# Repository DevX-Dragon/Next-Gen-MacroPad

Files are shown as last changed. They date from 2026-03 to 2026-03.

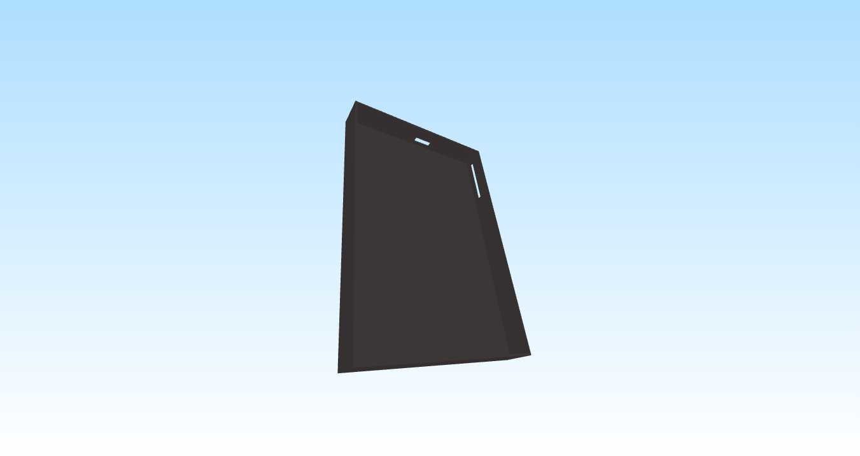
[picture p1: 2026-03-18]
images/Bottom Enclosure.png

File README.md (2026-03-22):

# NextGen Macropad
The Next-Gen MacroPad is a fully DIY, multi-purpose macro pad kit. It's got programmable keys, it looks cool, and most importantly — I made it. A 14-year-old made it. So if it breaks, don't be too surprised, but also it probably won't break because I tested it a bunch.

## Specifications
- 16 Programmable Keys
- 0.96 OLED Display
- Both Bluetooth and USB C connectivity
- Per Key RGB

## Layout
### KiCad
Schematics
PCB

### 3D
Bottom Enclosure
Top Cover

### Assembled
Assembled Preview
Side Side Loo

## Whats inside?
- `/3D Files` : 3D Files for 3D Printing and Source Files for your own modifcations.
- `/Firmware` : Firmware for the Macro Pad (CircuitPyhton)
- `/KiCad Files` : Soruce files for KiCad for your own modifications.
- `/Images` : Previews of multiple assets
- `/Production` : Prodution files for PCB manufacturings.
- `BOM.csv` : Price Breakdown and Links

## BOM
| Product Name | Needed Quanity | Price | Additonal Notes |
| --- | --- | --- | --- |
| [PCB and PCBA](https://jlcpcb.com/) | 1 | $ 110 | 5 PCB with 2 PCBA |
| [Key Switches](https://share.temu.com/qnOeKNn7wBB) | 16 | $ 35 | A pack of 35 switches |
| [Key Caps](https://www.aliexpress.com/item/1005004525231272.html) | 16 | $ 10 | Plain Key Caps, Pack of 20 |
| [OLED Display](https://www.duino.lk/product/oled-display-0-96-inche-blue-yellow/) | 1 | $ 4 | Local Hardware Store |
| [6x6x5mm THT Push Buttons](https://www.duino.lk/product/tactile-push-button-switch-2pins-6x6x5mm/) | 2 | $ 1 | Local hardware Store |
| [SK6812 Mini E LED](https://www.aliexpress.com/item/1005008308801366.html) | 16 | $ 1 | Pack of 20 | 
| 3D Printing | 1 | $ 15 | Printing Legion |
| | **Total** | **$ 176** |

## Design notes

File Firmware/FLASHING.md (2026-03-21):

# Flashing the MacroPad Firmware

Okay so this is actually pretty easy, don't panic.

---

## Step 1 — Install CircuitPython on the ESP32-S3

1. Go to [circuitpython.org/downloads](https://circuitpython.org/downloads) and search **ESP32-S3**.  
   Pick the variant that matches your exact board (check the flash size — usually 4MB or 8MB).

2. Hold the **BOOT** button on your ESP32-S3 and plug it into USB.  
   It should show up as a drive called `ESP32S3` or similar.

3. Drag the downloaded `.bin` file onto that drive (or use `esptool` if it doesn't show up as a drive).

4. It'll reboot and show up as a `CIRCUITPY` drive. You're done with this step.

---

## Step 2 — Install the libraries

1. Download the **CircuitPython Library Bundle** for your version from [circuitpython.org/libraries](https://circuitpython.org/libraries).

2. Unzip it. Inside you'll find a `lib/` folder with a ton of `.mpy` files.

3. Copy these specific folders/files into the `lib/` folder on your `CIRCUITPY` drive:

```
adafruit_hid/
adafruit_neopixel/          (just neopixel.mpy actually)
adafruit_display_text/
adafruit_displayio_ssd1306.mpy
adafruit_ble/
adafruit_ble_services/
```

> If you don't want Bluetooth, you can skip the `adafruit_ble` ones. Just set USB_MODE stuff and don't flip the mode switch.

---

## Step 3 — Copy the firmware files

Copy all of these onto the root of your `CIRCUITPY` drive:

```
boot.py
code.py
config.py
keymap.py
```

Your drive should look like:
```
CIRCUITPY/
├── boot.py
├── code.py
├── config.py
├── keymap.py
└── lib/
    ├── adafruit_hid/
    ├── neopixel.mpy
    ├── adafruit_display_text/
    ├── adafruit_displayio_ssd1306.mpy
    ├── adafruit_ble/
    └── adafruit_ble_services/
```

---

## Step 4 — Update config.py for your wiring

Open `config.py` and check the pin numbers match how you actually wired things.  
The defaults are:

| Thing | Pins |
|---|---|
| Row pins | GPIO1–GPIO4 |
| Col pins | GPIO5–GPIO8 |
| NeoPixel data | GPIO18 |
| OLED SDA | GPIO9 |
| OLED SCL | GPIO10 |
| Mode switch | GPIO12 |

If yours are different, just change the numbers. That's literally all you have to do.

---

## Step 5 — Plug it in and test

- **USB mode**: keep the mode switch HIGH (or just leave GPIO0 floating — it's pulled up by default). It should show up as a USB keyboard.
- **Bluetooth mode**: flip the switch to pull GPIO0 LOW before plugging in. Look for "Next-Gen MacroPad" in your Bluetooth devices.

The OLED should show the current layer and mode. LEDs should light up. Press a key and something should happen.

If nothing happens, open a serial monitor (Mu editor works great, or PuTTY/screen) and check for error messages.

---

## Troubleshooting

**OLED is blank**  
→ Check I2C address. Try `0x3D` in config.py if `0x3C` doesn't work.  
→ Double-check SDA/SCL wiring.

**Keys don't register**  
→ Check your ROW_PINS and COL_PINS in config.py.  
→ Make sure diodes are the right way around (cathode toward column).

**Bluetooth won't pair**  
→ Make sure GPIO0 is pulled LOW *before* powering on (boot.py reads it at startup).  
→ Delete the device from your PC's Bluetooth list and try again.

**LEDs wrong color or not lighting**  
→ Check NEOPIXEL_PIN in config.py.  
→ Some NeoPixel strips are RGB not GRB — change `pixel_order=neopixel.GRB` to `RGB` in code.py.

**Import errors on boot**  
→ A library is missing from `/lib`. Check the error message — it'll tell you exactly which one.

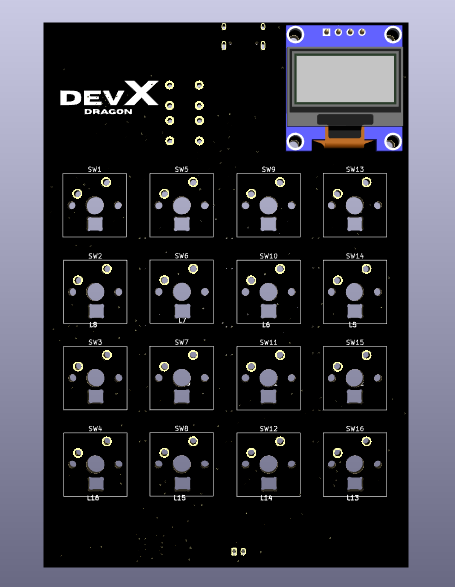
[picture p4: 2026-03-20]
images/PCB 3D Front.png

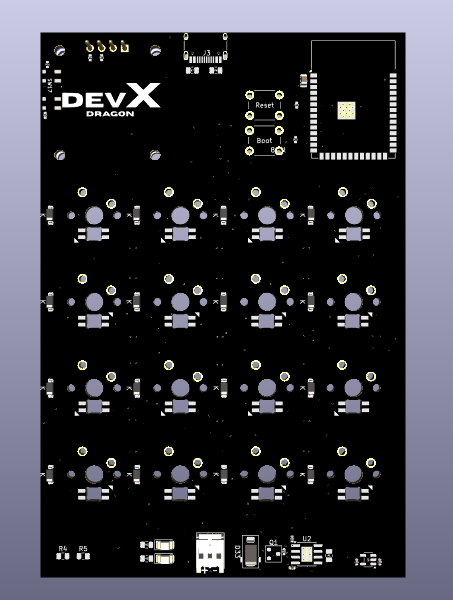
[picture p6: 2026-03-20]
images/PCB 3D Back.png

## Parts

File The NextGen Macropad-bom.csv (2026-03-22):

Name | Purpose | Quantity | Total Cost (USD) | Link | Distributor
3D Printing | The Case | May get it from Printing Legion but costs too high (more than 15 for India) | 1 | 10.00 |  | duino.lk Local
PCB and PCBA | main thing | 1 | 110.00 |  | JLC PCB

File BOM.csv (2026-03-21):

Product Name | Quanity | Total Price | Notes | Link
PCBA | 5 | $110.00 | 5 PCB w/ 2 PCBA | JLC PCB
Key Switches | 16 | $35.00 | Pack of 35 | https://share.temu.com/qnOeKNn7wBB
Key Caps | 16 | $10.00 | Pack of 20 | https://www.aliexpress.com/item/1005004525231272.html
3D Print | 1 | $10.00 | mostly planning on getting it on duino.lk as printing legion is expensive for Sri Lanka
OLED display | 1 | $4.00 |  | https://www.duino.lk/product/oled-display-0-96-inche-blue-yellow/
6x6x5 THT Push button | 1 | $1.00 |  | https://www.duino.lk/product/tactile-push-button-switch-2pins-6x6x5mm/
 | Total | $170.00

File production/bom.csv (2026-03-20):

Designator | Footprint | Quantity | Value | LCSC Part #
C1, C2 | 0402 | 2 | 1uF
C3 | 0805 | 1 | 1uF
C4, C5 | 0402 | 2 | 10uF
D1, D10, D11, D12, D13, D14, D15, D16, D2, D3, D4, D5, D6, D7, D8, D9 | Diode_SOD-123 | 16 | D
D17 | 1206 | 1 | Charging | C2298
D18 | 1206 | 1 | Fully Charged | C2298
D33 | D_SMA | 1 | SS14
J1 | OLED_128x64 | 1 | OLED_128x64
J2 | JST_PH_S2B-PH-K_1x02_P2.00mm_Horizontal | 1 | Battery JST-PH
J3 | USB_C_Receptacle_HRO_TYPE-C-31-M-12 | 1 | USB_C_Receptacle_USB2.0_16P | C165948
L1, L10, L11, L12, L13, L14, L15, L16, L2, L3, L4, L5, L6, L7, L8, L9 | SK6812MINI-E_fixed | 16 | SK6812
Q1 | SOT-23 | 1 | AO3401A
R1 | 0805 | 1 | 2.4k
R10, R8 | 0402 | 2 | 100k
R11, R12, R9 | 0402 | 3 | 10k
R13, R14 | 0402 | 2 | 4.7k
R2, R3 | 0805 | 2 | 1k
R4, R5 | 0805 | 2 | 100k
R6, R7 | 0805 | 2 | 5.1k
SW1, SW10, SW11, SW12, SW13, SW14, SW15, SW16, SW2, SW3, SW4, SW5, SW6, SW7, SW8, SW9 | SW_Cherry_MX_1.00u_PCB | 16 | SW_Push_45deg
SW17 | CL-SB-23A-11T | 1 | SW_DP3T
SW18 | SW_PUSH_6mm | 1 | Reset | C42416254
SW19 | SW_PUSH_6mm | 1 | Boot | C42416254
U1 | ESP32-S3-WROOM-1 | 1 | ESP32-S3-WROOM-1
U2 | SOIC-8-1EP_3.9x4.9mm_P1.27mm_EP2.41x3.3mm_ThermalVias | 1 | TP4056-42-ESOP8 | C16581
U3 | SOT-23-5 | 1 | AP2112K-3.3 | C23380830

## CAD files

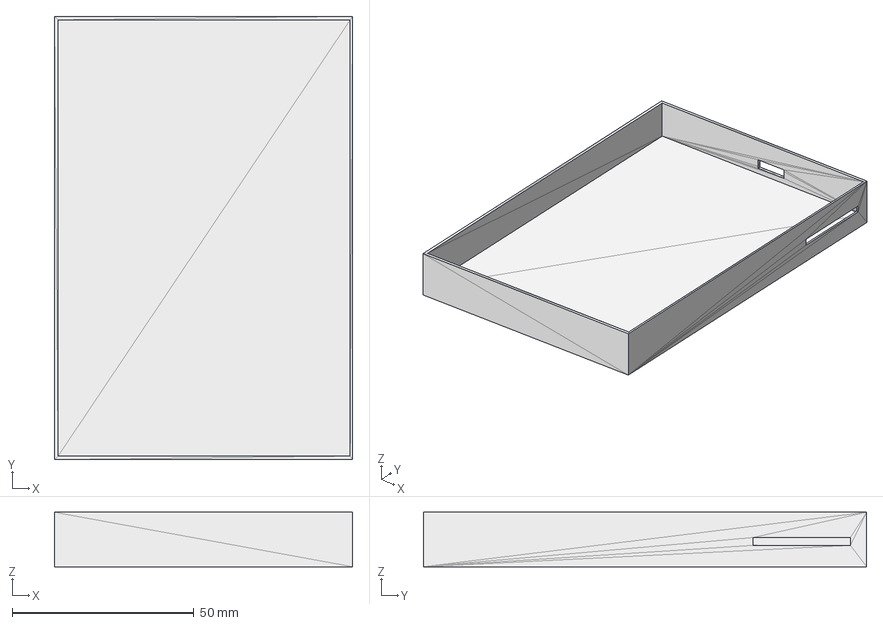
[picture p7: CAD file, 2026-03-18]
3D Files/Case/.STEP files/Bottom Enclosure.step
82.0 x 122.0 x 15.0 mm

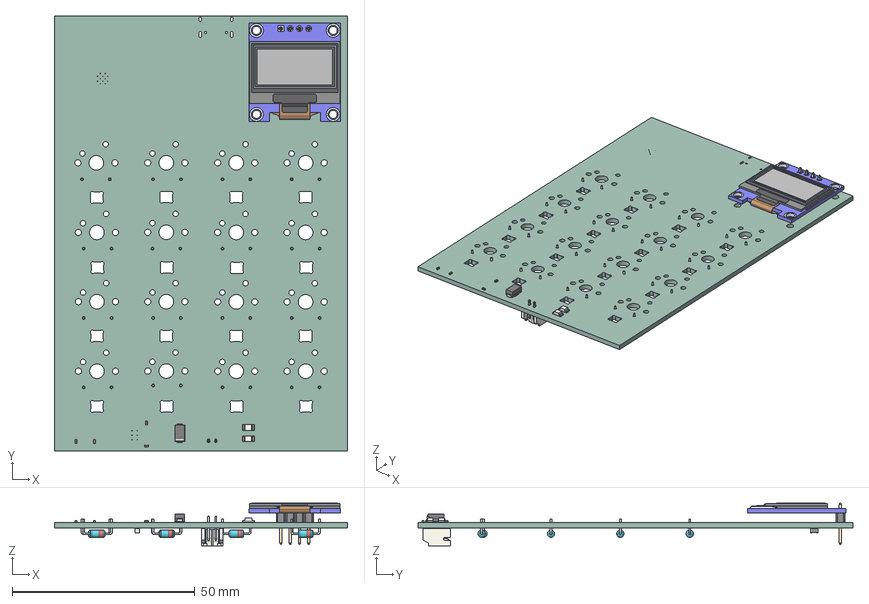
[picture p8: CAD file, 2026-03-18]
3D Files/PCB 3D Files/NextGen Macropad.step
80.4 x 119.2 x 11.8 mm
LED_1206_3216Metric x 2
C_0402_1005Metric x 4
OLED
D_SMA
Diode_DO-35 x 16
C_0805_2012Metric
JST_PH_S2B-PH-K_1x02_P2.00mm_Horizontal
NextGen Macropad_PCB

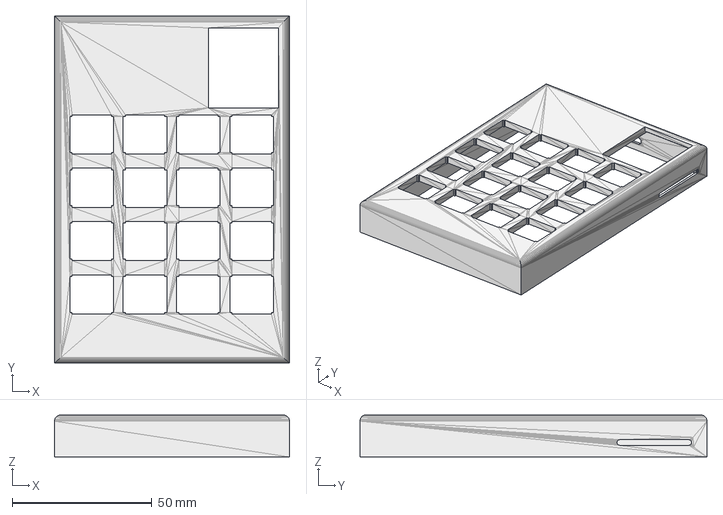
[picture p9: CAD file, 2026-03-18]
3D Files/Case/.STEP files/Top Enclosure.step
84.0 x 124.0 x 15.0 mm

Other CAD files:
3D Files/Case Source.blend
3D Files/Case/.STL files/Bottom Enclosure.stl
3D Files/Case/.STL files/Top Enclosure.stl

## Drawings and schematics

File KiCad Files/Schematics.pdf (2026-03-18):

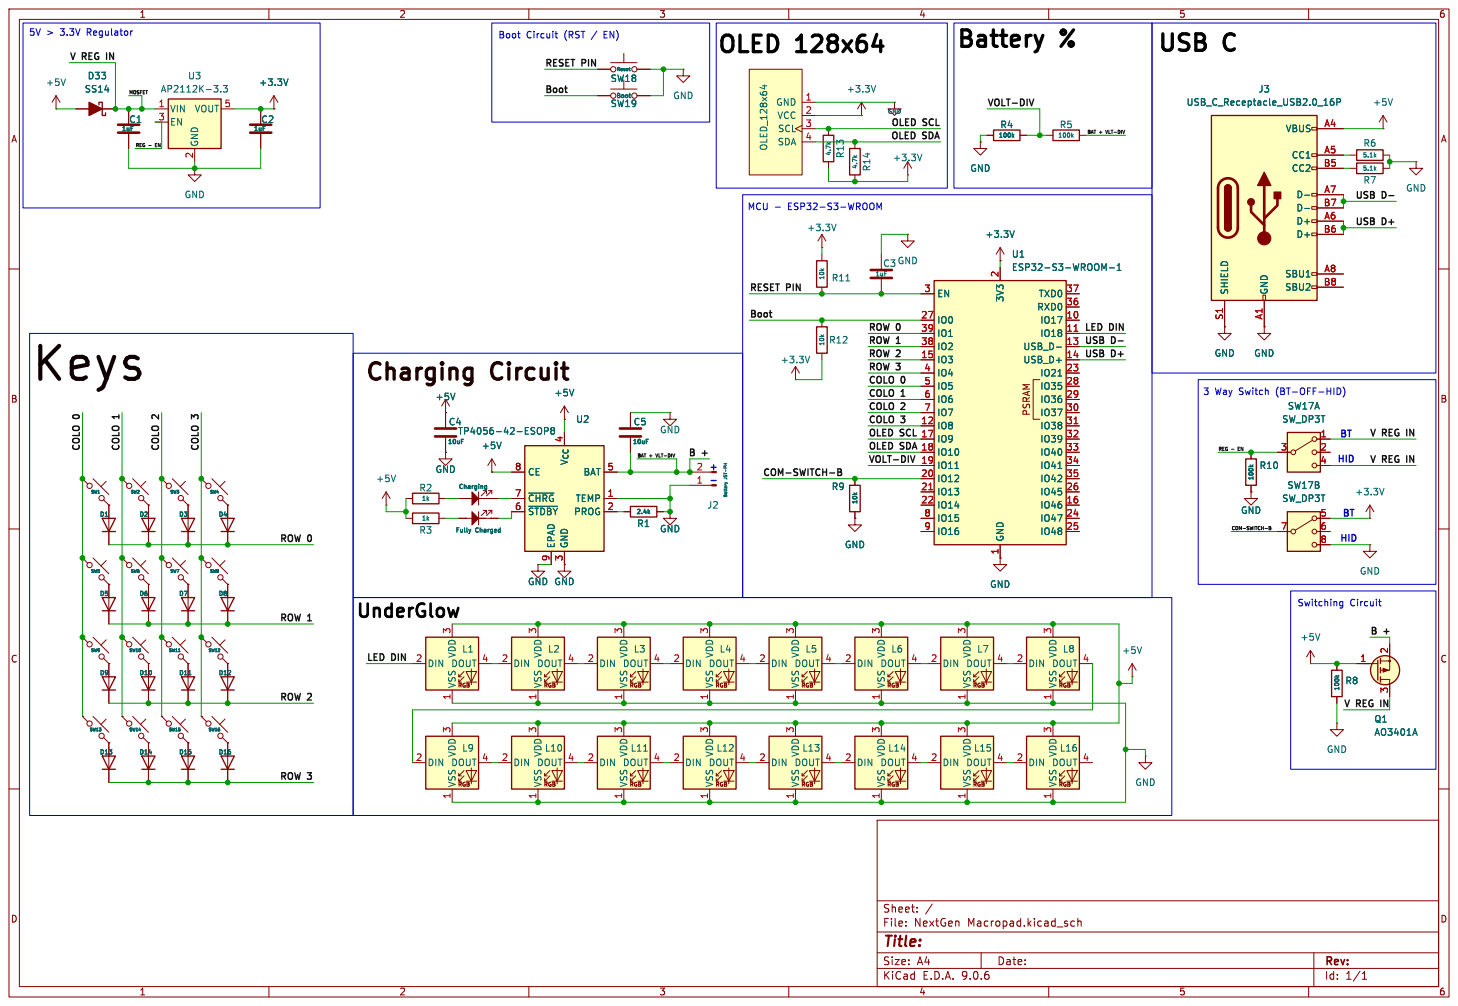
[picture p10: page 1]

2 3 R8 100k J3 USB_C_Receptacle_USB2.0_16P SHIELD S1 GND A1 VBUS A4 CC1 A5 CC2 B5 D- A7 D- B7 D+ A6 D+ B6 SBU1 A8 SBU2 B8 GND GND GND

COM-SWITCH-B USB D- USB D+ RESET PIN

J2 Battery JST-PH GND

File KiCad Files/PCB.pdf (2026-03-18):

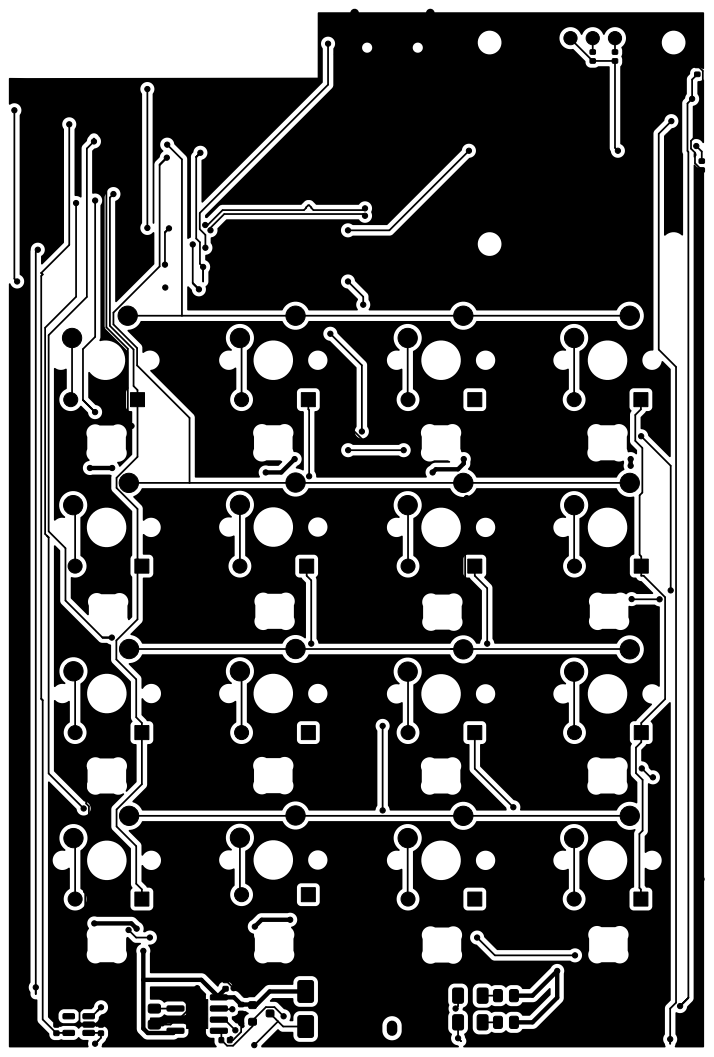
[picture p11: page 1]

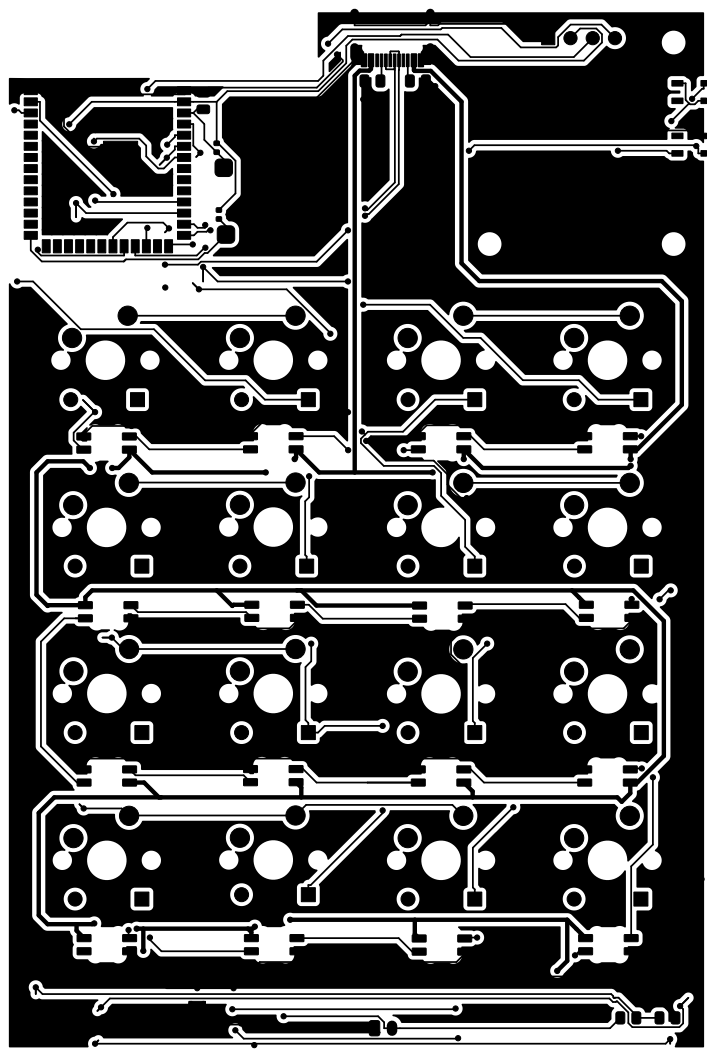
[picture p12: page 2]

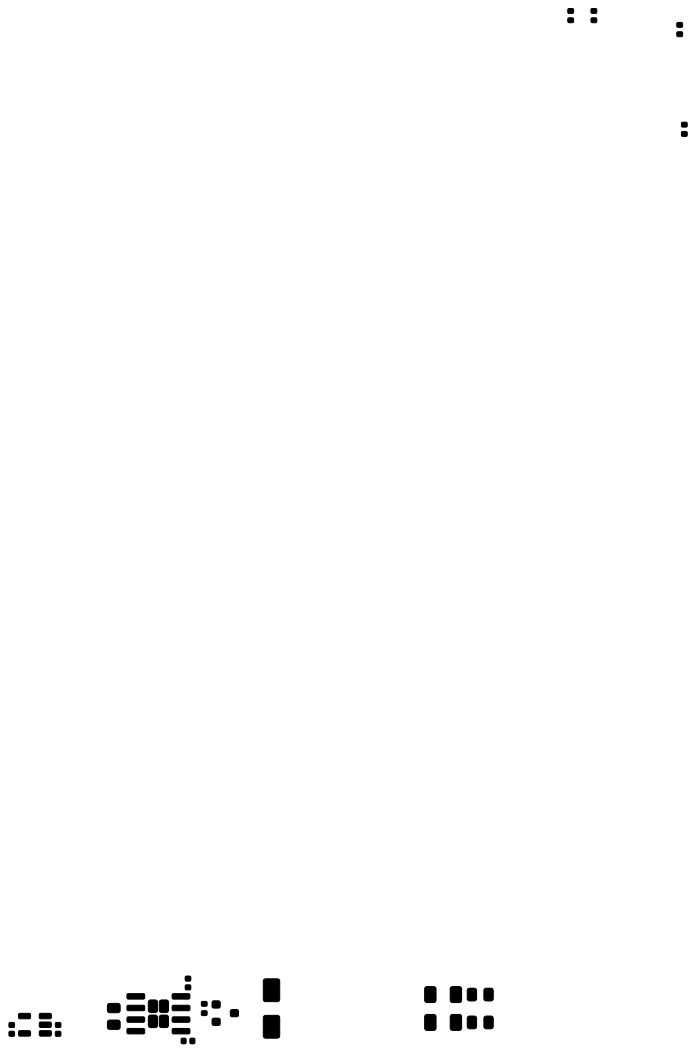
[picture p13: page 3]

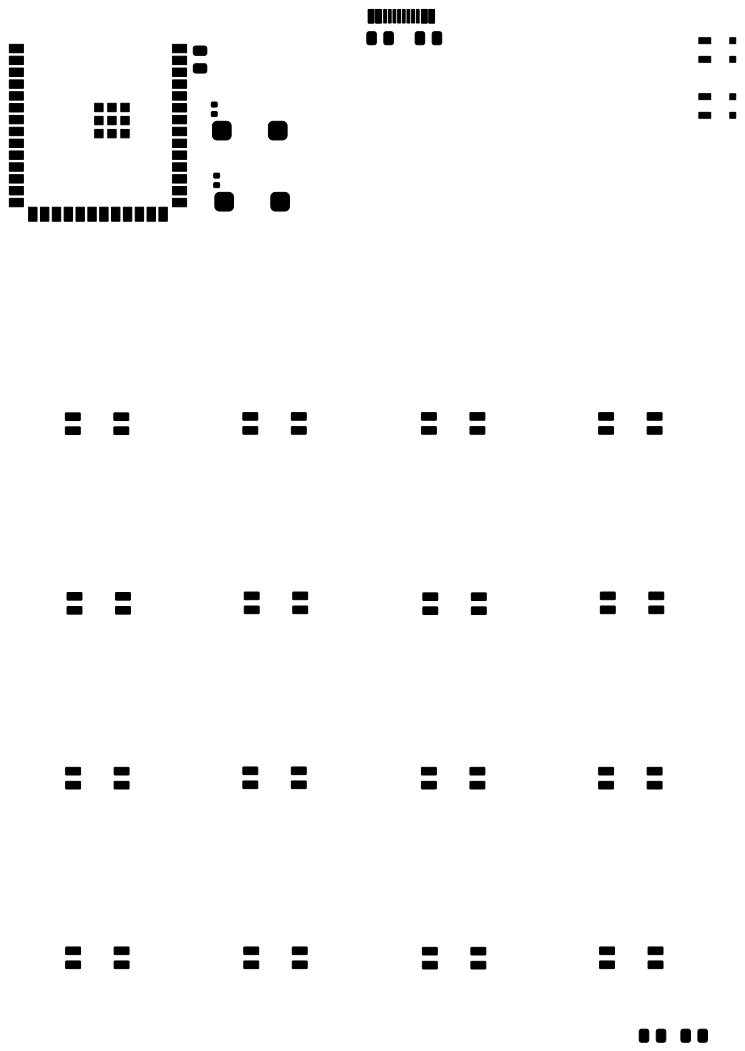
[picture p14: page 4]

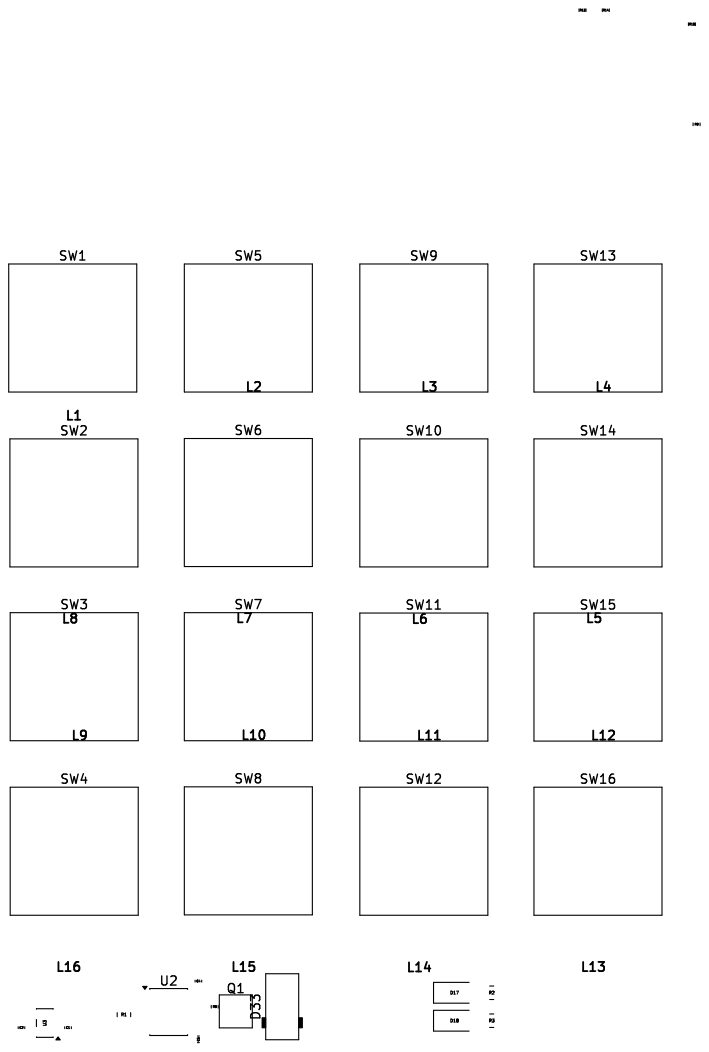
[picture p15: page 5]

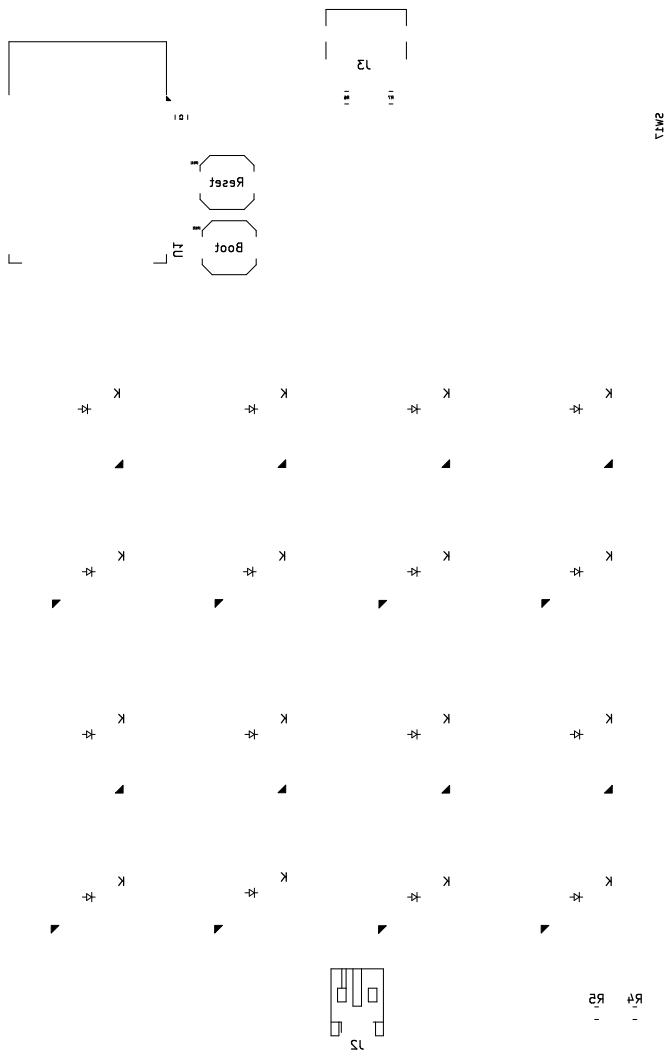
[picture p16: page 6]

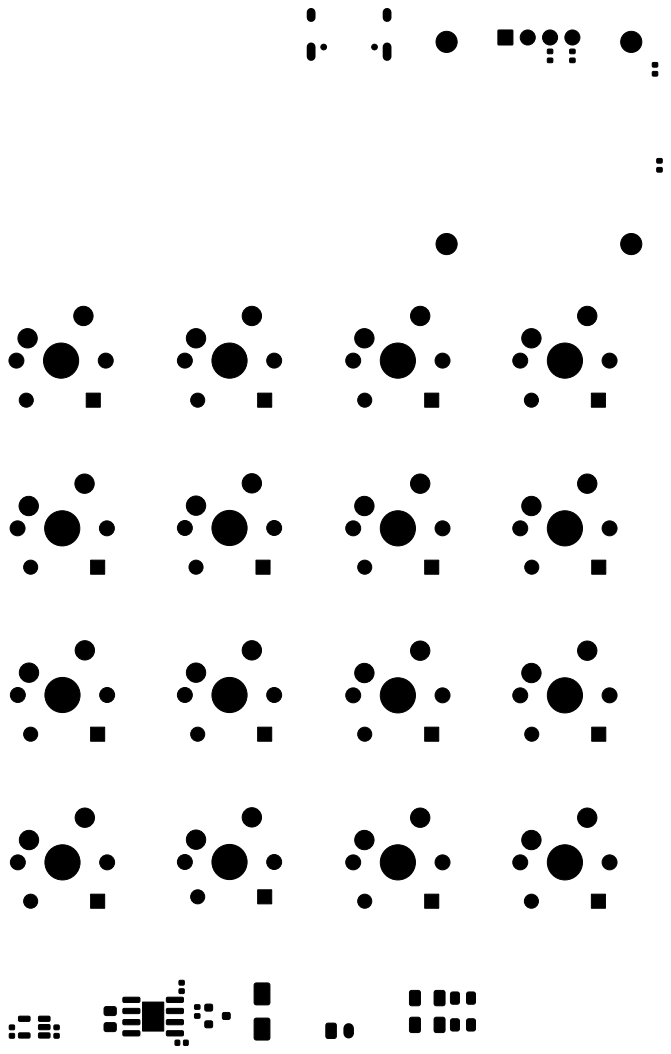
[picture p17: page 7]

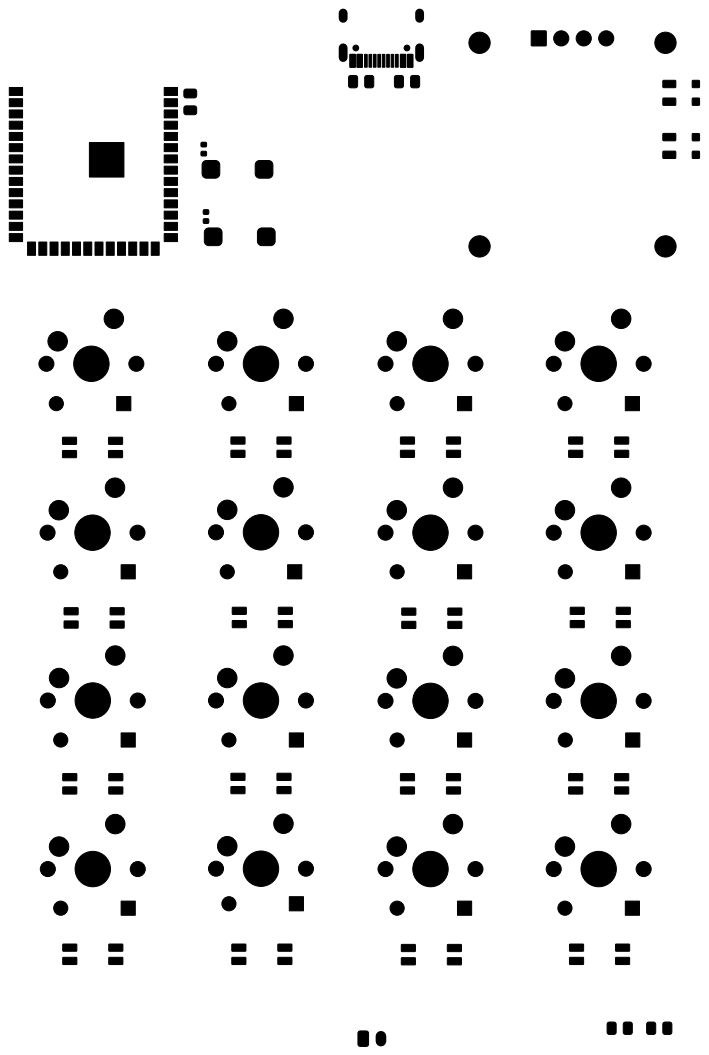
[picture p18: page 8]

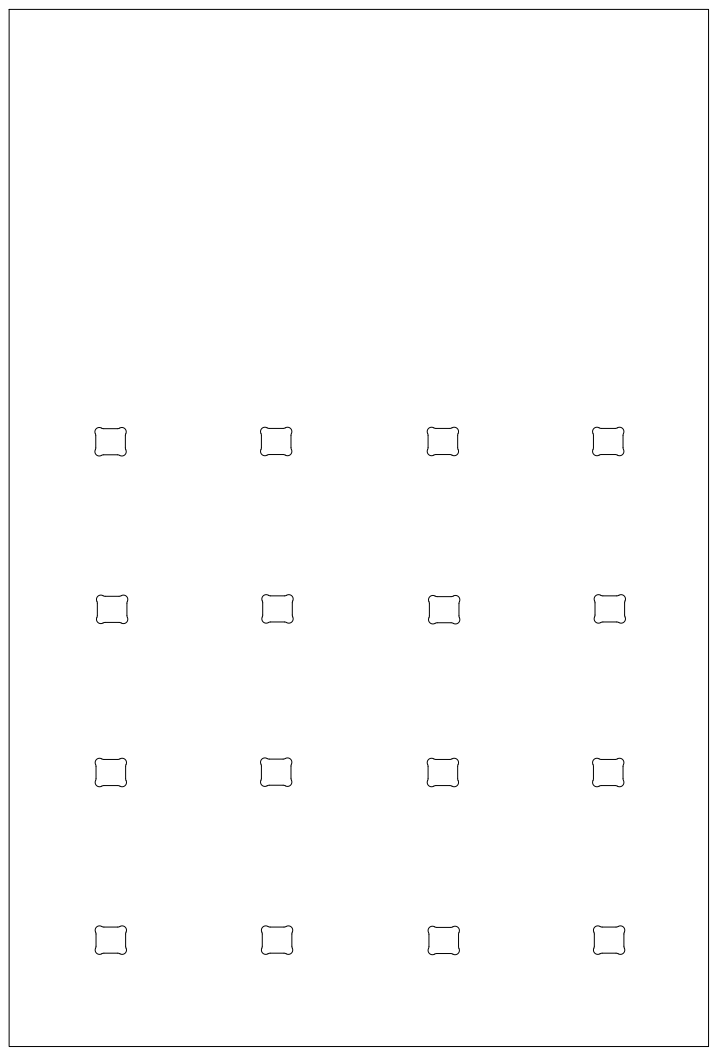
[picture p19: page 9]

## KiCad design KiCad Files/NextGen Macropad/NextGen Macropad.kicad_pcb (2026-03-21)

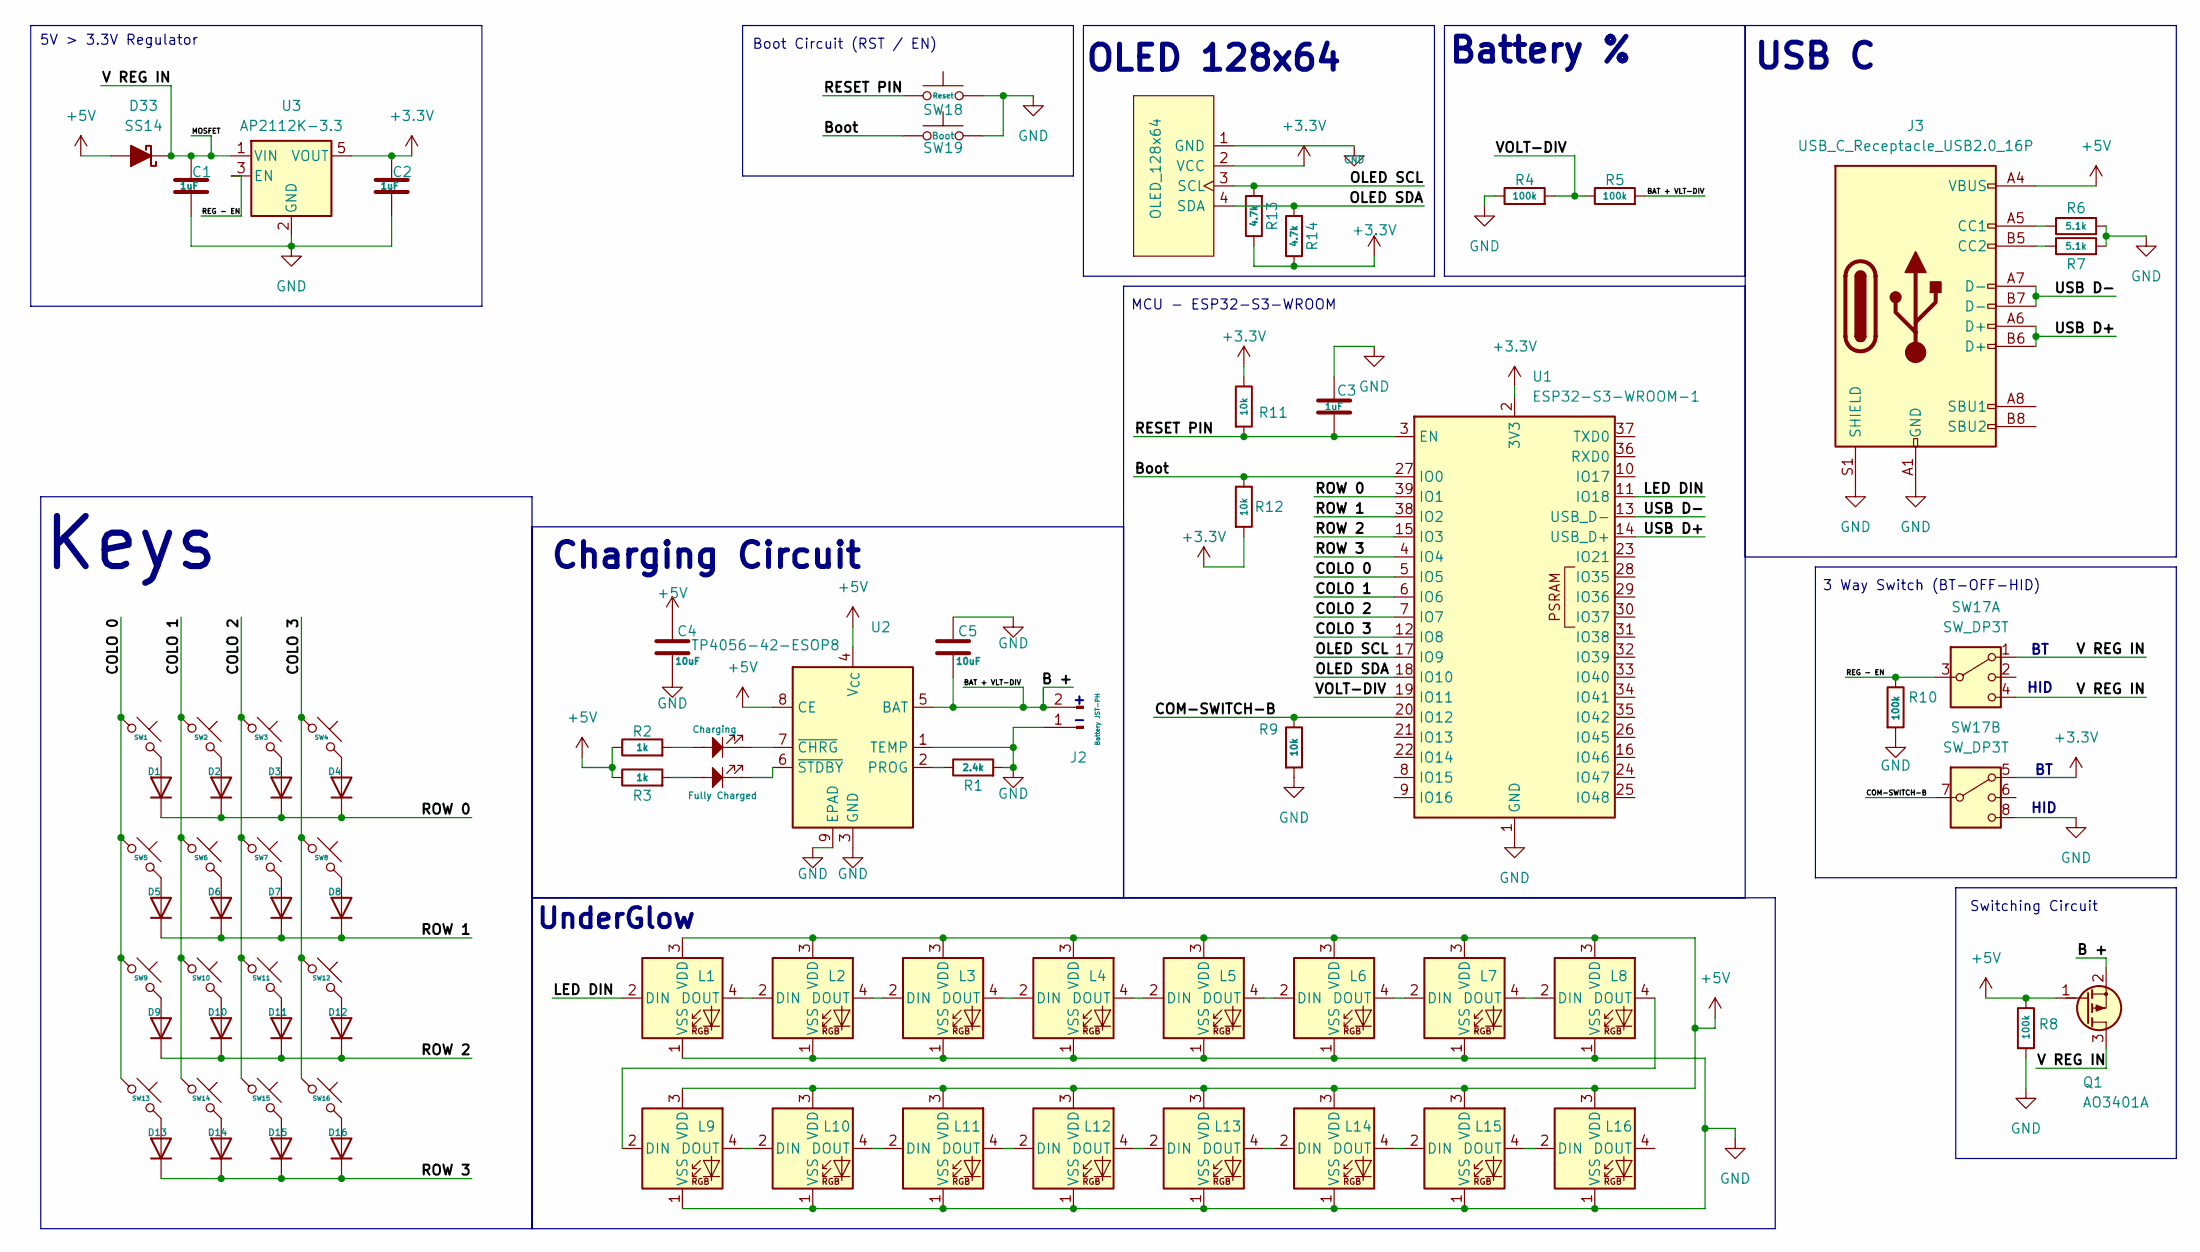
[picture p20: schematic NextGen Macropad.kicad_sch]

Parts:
C1, C2, C3: 1uF; C_0805_2012Metric
C4, C5: 10uF; C_0805_2012Metric
D1, D2, D3, D4, D5, D6, D7, D8, D9, D10, D11, D12, D13, D14, D15, D16: D; D_DO-35_SOD27_P7.62mm_Horizontal
D17: Charging; LED_1206_3216Metric; LCSC C2298
D18: Fully Charged; LED_1206_3216Metric; LCSC C2298
D33: SS14; D_SMA
J1: OLED_128x64
J2: Battery JST-PH; JST_PH_S2B-PH-K_1x02_P2.00mm_Horizontal
J3: USB_C_Receptacle_USB2.0_16P; USB_C_Receptacle_HRO_TYPE-C-31-M-12; LCSC C165948
L1, L2, L3, L4, L5, L6, L7, L8, L9, L10, L11, L12, L13, L14, L15, L16: SK6812; SK6812MINI-E_fixed
Q1: AO3401A; SOT-23
R1: 2.4k; R_0805_2012Metric
R2, R3: 1k; R_0805_2012Metric
R4, R5, R8, R10: 100k; R_0805_2012Metric
R6, R7: 5.1k; R_0805_2012Metric
R9, R11, R12: 10k; R_0805_2012Metric
R13, R14: 4.7k; R_0805_2012Metric
SW1, SW2, SW3, SW4, SW5, SW6, SW7, SW8, SW9, SW10, SW11, SW12, SW13, SW14, SW15, SW16: SW_Push_45deg; SW_Cherry_MX_1.00u_PCB
SW17: SW_DP3T; CL-SB-23A-11T
SW18: Reset; SW_Push_1TS009xxxx-xxxx-xxxx_6x6x5mm; LCSC C42416254
SW19: Boot; SW_Push_1TS009xxxx-xxxx-xxxx_6x6x5mm; LCSC C42416254
U1: ESP32-S3-WROOM-1
U2: TP4056-42-ESOP8; SOIC-8-1EP_3.9x4.9mm_P1.27mm_EP2.41x3.3mm_ThermalVias; LCSC C16581
U3: AP2112K-3.3; SOT-23-5; LCSC C23380830

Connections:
+3.3V: C2.1, J1.2 (VCC), R11.1, R12.2, R13.1, R14.1, SW17.5, U1.2 (3V3), U3.5 (VOUT)
+5V: C4.1, D33.2 (A), J3.A4 (VBUS), J3.A9 (VBUS), J3.B4 (VBUS), J3.B9 (VBUS), L1.3 (VDD), L2.3 (VDD), L3.3 (VDD), L4.3 (VDD), L5.3 (VDD), L6.3 (VDD), L7.3 (VDD), L8.3 (VDD), L9.3 (VDD), L10.3 (VDD), L11.3 (VDD), L12.3 (VDD), L13.3 (VDD), L14.3 (VDD), L15.3 (VDD), L16.3 (VDD), Q1.1 (G), R2.1, R3.1, R8.1, U2.4 (V_{CC}), U2.8 (CE)
/B +: C5.2, J2.2, Q1.2 (S), R5.2, U2.5 (BAT)
/Boot: R12.1, SW19.1, U1.27 (IO0)
/COLO 0: SW1.1, SW5.1, SW9.1, SW13.1, U1.5 (IO5)
/COLO 1: SW2.1, SW6.1, SW10.1, SW14.1, U1.6 (IO6)
/COLO 2: SW3.1, SW7.1, SW11.1, SW15.1, U1.7 (IO7)
/COLO 3: SW4.1, SW8.1, SW12.1, SW16.1, U1.12 (IO8)
/COM-SWITCH-B: R9.1, SW17.7, U1.20 (IO12)
/LED DIN: L1.2 (DIN), U1.11 (IO18)
/MOSFET: C1.1, D33.1 (K), Q1.3 (D), SW17.1, SW17.4, U3.1 (VIN)
/OLED SCL: J1.3 (SCL), R13.2, U1.17 (IO9)
/OLED SDA: J1.4 (SDA), R14.2, U1.18 (IO10)
/REG - EN: R10.1, SW17.3, U3.3 (EN)
/RESET PIN: C3.2, R11.2, SW18.1, U1.3 (EN)
/ROW 0: D1.1 (K), D2.1 (K), D3.1 (K), D4.1 (K), U1.39 (IO1)
/ROW 1: D5.1 (K), D6.1 (K), D7.1 (K), D8.1 (K), U1.38 (IO2)
/ROW 2: D9.1 (K), D10.1 (K), D11.1 (K), D12.1 (K), U1.15 (IO3)
/ROW 3: D13.1 (K), D14.1 (K), D15.1 (K), D16.1 (K), U1.4 (IO4)
/USB D+: J3.A6 (D+), J3.B6 (D+), U1.14 (USB_D+)
/USB D-: J3.A7 (D-), J3.B7 (D-), U1.13 (USB_D-)
/VOLT-DIV: R4.2, R5.1, U1.19 (IO11)
GND: C1.2, C2.2, C3.1, C4.2, C5.1, J1.1 (GND), J2.1, J3.A1 (GND), J3.A12 (GND), J3.B1 (GND), J3.B12 (GND), J3.S1 (SHIELD), L1.1 (VSS), L2.1 (VSS), L3.1 (VSS), L4.1 (VSS), L5.1 (VSS), L6.1 (VSS), L7.1 (VSS), L8.1 (VSS), L9.1 (VSS), L10.1 (VSS), L11.1 (VSS), L12.1 (VSS), L13.1 (VSS), L14.1 (VSS), L15.1 (VSS), L16.1 (VSS), R1.2, R4.1, R6.2, R7.2, R8.2, R9.2, R10.2, SW17.8, SW18.2, SW19.2, U1.1 (GND), U1.40 (GND), U1.41 (GND), U2.1 (TEMP), U2.3 (GND), U2.9 (EPAD), U3.2 (GND)
unnamed: D1.2 (A), SW1.2
unnamed: D2.2 (A), SW2.2
unnamed: D3.2 (A), SW3.2
unnamed: D4.2 (A), SW4.2
unnamed: D5.2 (A), SW5.2
unnamed: D6.2 (A), SW6.2
unnamed: D7.2 (A), SW7.2
unnamed: D8.2 (A), SW8.2
unnamed: D9.2 (A), SW9.2
unnamed: D10.2 (A), SW10.2
unnamed: D11.2 (A), SW11.2
unnamed: D12.2 (A), SW12.2
unnamed: D13.2 (A), SW13.2
unnamed: D14.2 (A), SW14.2
unnamed: D15.2 (A), SW15.2
unnamed: D16.2 (A), SW16.2
unnamed: D17.2, R2.2
unnamed: D18.2, R3.2
unnamed: J3.A5 (CC1), R6.1
unnamed: J3.B5 (CC2), R7.1
unnamed: L1.4 (DOUT), L2.2 (DIN)
unnamed: L2.4 (DOUT), L3.2 (DIN)
unnamed: L3.4 (DOUT), L4.2 (DIN)
unnamed: L4.4 (DOUT), L5.2 (DIN)
unnamed: L5.4 (DOUT), L6.2 (DIN)
unnamed: L6.4 (DOUT), L7.2 (DIN)
unnamed: L7.4 (DOUT), L8.2 (DIN)
unnamed: L8.4 (DOUT), L9.2 (DIN)
unnamed: L9.4 (DOUT), L10.2 (DIN)
unnamed: L10.4 (DOUT), L11.2 (DIN)
unnamed: L11.4 (DOUT), L12.2 (DIN)
unnamed: L12.4 (DOUT), L13.2 (DIN)
unnamed: L13.4 (DOUT), L14.2 (DIN)
unnamed: L14.4 (DOUT), L15.2 (DIN)
unnamed: L15.4 (DOUT), L16.2 (DIN)
unnamed: R1.1, U2.2 (PROG)
unnamed: D17.1, U2.7 (~CHRG)
unnamed: D18.1, U2.6 (~STDBY)

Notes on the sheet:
3 Way Switch (BT-OFF-HID)
MCU - ESP32-S3-WROOM
Boot Circuit (RST / EN)
Switching Circuit
OLED 128x64
UnderGlow
HID
Charging Circuit
5V > 3.3V Regulator
USB C
Keys
Battery %

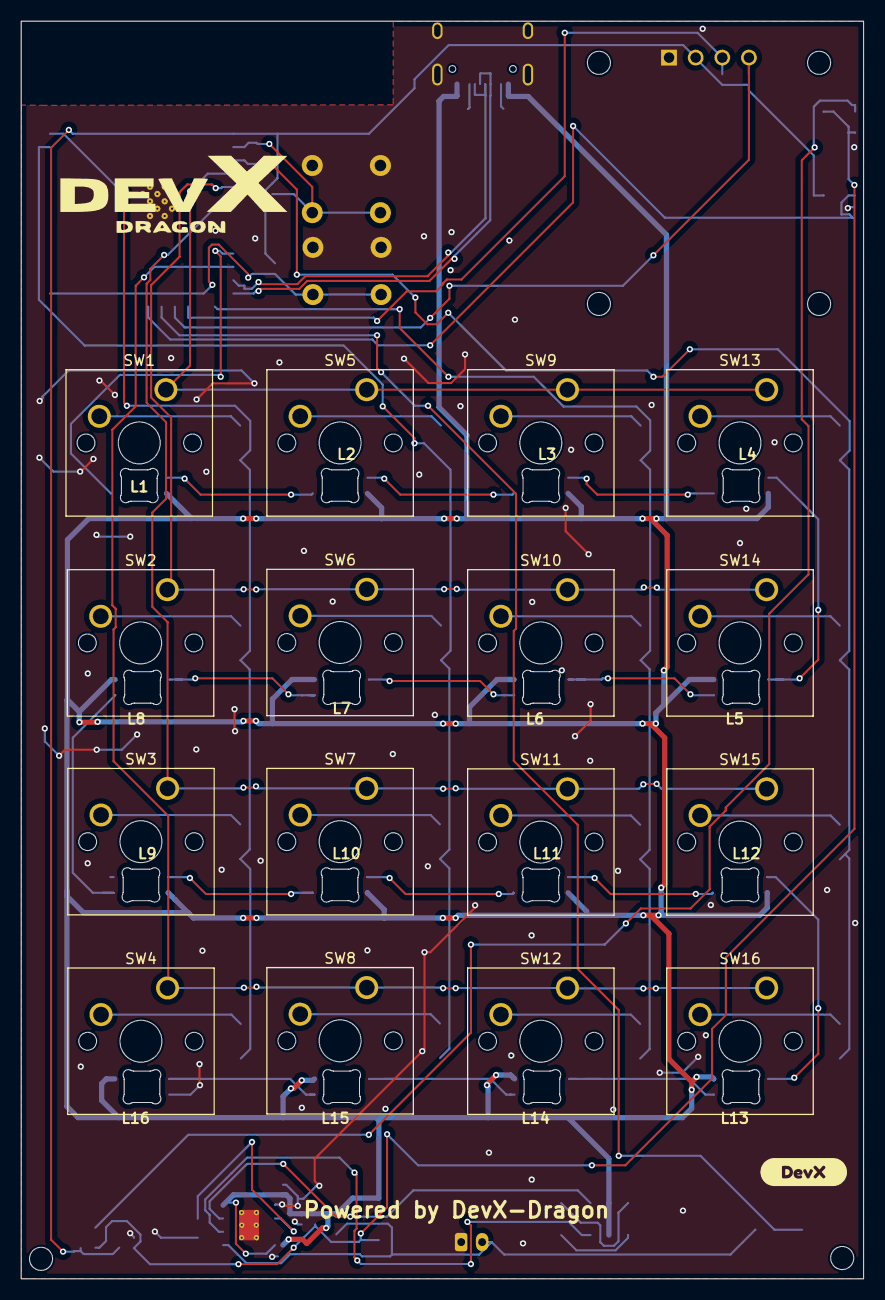
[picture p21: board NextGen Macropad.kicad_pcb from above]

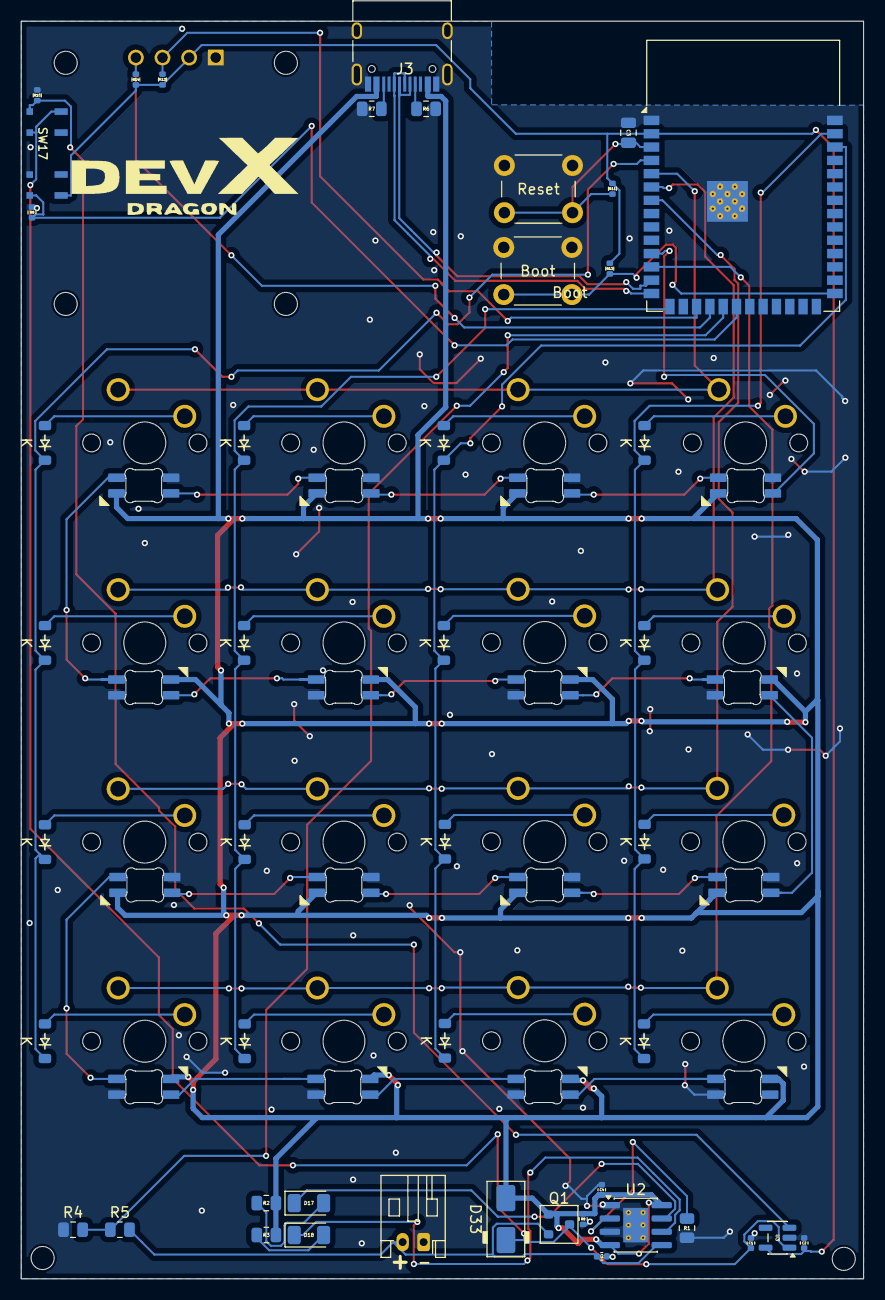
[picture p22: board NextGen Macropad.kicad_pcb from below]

Board: 2 copper layers, 80.4 x 120.0 mm, 81 parts (47 on the bottom side), 61 nets.

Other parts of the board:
kibuzzard-69BEA4AE: G***; kibuzzard-69BEA4AE

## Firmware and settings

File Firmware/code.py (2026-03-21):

# code.py — Next-Gen MacroPad firmware
# ESP32-S3 | CircuitPython | 4x4 matrix | NeoPixels | OLED | USB+BT
# by Dragon (DevX-Dragon) — github.com/DevX-Dragon

import time
import board
import busio
import digitalio
import neopixel
import displayio
import terminalio
import supervisor

from adafruit_display_text import label
from adafruit_displayio_ssd1306 import SSD1306
import adafruit_displayio_ssd1306

import usb_hid
from adafruit_hid.keyboard import Keyboard
from adafruit_hid.keyboard_layout_us import KeyboardLayoutUS
from adafruit_hid.keycode import Keycode
from adafruit_hid.consumer_control import ConsumerControl
from adafruit_hid.consumer_control_code import ConsumerControlCode

import config
import keymap

# ─── DETECT MODE (set in boot.py via GPIO0) ───────────────────────────────────
_mode_pin = digitalio.DigitalInOut(config.MODE_PIN)
_mode_pin.direction = digitalio.Direction.INPUT
_mode_pin.pull = digitalio.Pull.UP
USB_MODE = _mode_pin.value  # True = USB HID, False = Bluetooth


# ══════════════════════════════════════════════════════════════════════════════
# USB HID SETUP
# ══════════════════════════════════════════════════════════════════════════════
keyboard = None
layout   = None
consumer = None

if USB_MODE:
    try:
        keyboard = Keyboard(usb_hid.devices)
        layout   = KeyboardLayoutUS(keyboard)
        consumer = ConsumerControl(usb_hid.devices)
        print("[USB] HID ready")
    except Exception as e:
        print(f"[USB] HID init failed: {e}")
        USB_MODE = False


# ══════════════════════════════════════════════════════════════════════════════
# BLUETOOTH SETUP (ESP32-S3 via _bleio)
# ══════════════════════════════════════════════════════════════════════════════
bt_keyboard = None
bt_consumer = None

if not USB_MODE:
    try:
        from adafruit_ble import BLERadio
        from adafruit_ble.advertising.standard import ProvideServicesAdvertisement
        from adafruit_ble.services.standard.hid import HIDService
        from adafruit_ble.services.standard.device_info import DeviceInfoService

        ble         = BLERadio()
        ble.name    = config.BT_DEVICE_NAME
        hid_service = HIDService()
        device_info = DeviceInfoService(
            software_revision="1.0",
            manufacturer="DevX-Dragon"
        )
        advertisement = ProvideServicesAdvertisement(hid_service)

        bt_keyboard = Keyboard(hid_service.devices)
        layout      = KeyboardLayoutUS(bt_keyboard)
        bt_consumer = ConsumerControl(hid_service.devices)

        print("[BT] Advertising as:", config.BT_DEVICE_NAME)
        ble.start_advertising(advertisement)
    except Exception as e:
        print(f"[BT] Init failed: {e}")


# ══════════════════════════════════════════════════════════════════════════════
# NEOPIXELS
# ══════════════════════════════════════════════════════════════════════════════
pixels = neopixel.NeoPixel(
    config.NEOPIXEL_PIN,
    config.NEOPIXEL_COUNT,
    brightness=config.NEOPIXEL_BRIGHTNESS,
    auto_write=False,
    pixel_order=neopixel.GRB
)

# Breathing effect state
_breathe_val = 0.0
_breathe_dir = 1

# tracking when each key was last pressed for fade-out
_key_pressed_time = [0.0] * 16

def _hsv_to_rgb(h, s, v):
    """Convert HSV (0–1 each) to (r, g, b) 0–255."""
    if s == 0:
        c = int(v * 255)
        return (c, c, c)
    i = int(h * 6)
    f = h * 6 - i
    p, q, t = v*(1-s), v*(1-s*f), v*(1-s*(1-f))
    i %= 6
    if i == 0: r, g, b = v, t, p
    elif i == 1: r, g, b = q, v, p
    elif i == 2: r, g, b = p, v, t
    elif i == 3: r, g, b = p, q, v
    elif i == 4: r, g, b = t, p, v
    else:        r, g, b = v, p, q
    return (int(r*255), int(g*255), int(b*255))

def update_leds(current_layer, pressed_keys):
    global _breathe_val, _breathe_dir
    effect = config.RGB_EFFECT
    now    = time.monotonic()

    if effect == "solid":
        color = config.LAYER_COLORS[current_layer % len(config.LAYER_COLORS)]
        for i in range(config.NEOPIXEL_COUNT):
            pixels[i] = color

    elif effect == "rainbow":
        for i in range(config.NEOPIXEL_COUNT):
            hue = (i / config.NEOPIXEL_COUNT + now * 0.1) % 1.0
            pixels[i] = _hsv_to_rgb(hue, 1.0, 1.0)

    elif effect == "breathe":
        _breathe_val += 0.02 * _breathe_dir
        if _breathe_val >= 1.0: _breathe_dir = -1
        if _breathe_val <= 0.0: _breathe_dir =  1
        base = config.LAYER_COLORS[current_layer % len(config.LAYER_COLORS)]
        color = tuple(int(c * _breathe_val) for c in base)
        for i in range(config.NEOPIXEL_COUNT):
            pixels[i] = color

    elif effect == "reactive":
        for i in range(config.NEOPIXEL_COUNT):
            if i in pressed_keys:
                pixels[i] = config.RGB_PRESS_COLOR
                _key_pressed_time[i] = now
            else:
                age   = now - _key_pressed_time[i]
                fade  = max(0.0, 1.0 - age * 3.0)   # fades out over ~330ms
                base  = config.LAYER_COLORS[current_layer % len(config.LAYER_COLORS)]
                press = config.RGB_PRESS_COLOR
                r = int(press[0] * fade + base[0] * (1 - fade))
                g = int(press[1] * fade + base[1] * (1 - fade))
                b = int(press[2] * fade + base[2] * (1 - fade))
                pixels[i] = (r, g, b)

    pixels.show()


# ══════════════════════════════════════════════════════════════════════════════
# OLED DISPLAY
# ══════════════════════════════════════════════════════════════════════════════
displayio.release_displays()

i2c     = busio.I2C(config.OLED_SCL, config.OLED_SDA)
bus     = displayio.I2CDisplay(i2c, device_address=config.OLED_ADDR)
display = SSD1306(bus, width=config.OLED_WIDTH, height=config.OLED_HEIGHT)

LAYER_NAMES = ["General", "Streaming", "Coding", "Numpad"]

_last_activity  = time.monotonic()
_display_on     = True

def make_display_group(layer_idx, mode_str, last_key_str=""):
    """Build the displayio group shown on OLED."""
    group = displayio.Group()

    # Header bar
    header = label.Label(
        terminalio.FONT, text="Next-Gen MacroPad",
        color=0xFFFFFF, x=2, y=6
    )
    group.append(header)

    div_bmp = displayio.Bitmap(config.OLED_WIDTH, 1, 1)
    div_pal = displayio.Palette(1)
    div_pal[0] = 0xFFFFFF
    div = displayio.TileGrid(div_bmp, pixel_shader=div_pal, x=0, y=14)
    group.append(div)

    # Layer info
    layer_name = LAYER_NAMES[layer_idx] if layer_idx < len(LAYER_NAMES) else f"Layer {layer_idx}"
    layer_lbl  = label.Label(
        terminalio.FONT,
        text=f"Layer {layer_idx}: {layer_name}",
        color=0xFFFFFF, x=2, y=26
    )
    group.append(layer_lbl)

    # Mode (USB / BT)
    mode_lbl = label.Label(
        terminalio.FONT, text=mode_str,
        color=0xFFFFFF, x=2, y=40
    )
    group.append(mode_lbl)

    # Last key hint
    if last_key_str:
        key_lbl = label.Label(
            terminalio.FONT, text=last_key_str,
            color=0xFFFFFF, x=2, y=54
        )
        group.append(key_lbl)

    return group

def refresh_display(layer_idx, last_key=""):
    global _display_on
    mode_str = "Mode: USB HID" if USB_MODE else "Mode: Bluetooth"
    display.root_group = make_display_group(layer_idx, mode_str, last_key)
    _display_on = True

def dim_display():
    global _display_on
    if _display_on:
        display.root_group = displayio.Group()  # blank
        _display_on = False


# ══════════════════════════════════════════════════════════════════════════════
# KEY MATRIX
# ══════════════════════════════════════════════════════════════════════════════
rows = []
for pin in config.ROW_PINS:
    r = digitalio.DigitalInOut(pin)
    r.direction = digitalio.Direction.OUTPUT
    r.value = False
    rows.append(r)

cols = []
for pin in config.COL_PINS:
    c = digitalio.DigitalInOut(pin)
    c.direction = digitalio.Direction.INPUT
    c.pull = digitalio.Pull.DOWN
    cols.append(c)

_prev_state = [False] * 16
_debounce   = [0.0]  * 16


def scan_matrix():
    """Return list of currently pressed key indices."""
    pressed = []
    for r_idx, row in enumerate(rows):
        row.value = True
        time.sleep(0.001)
        for c_idx, col in enumerate(cols):
            if col.value:
                pressed.append(r_idx * 4 + c_idx)
        row.value = False
    return pressed


# ══════════════════════════════════════════════════════════════════════════════
# KEY ACTION 
# ══════════════════════════════════════════════════════════════════════════════
current_layer   = 0
_last_key_label = ""

def do_press(action):
    """Execute a key action on press."""
    global current_layer, _last_key_label

    atype = action[0]

    if atype == "none":
        return

    elif atype == "key":
        kc = action[1]
        _last_key_label = f"Key: {kc}"
        if USB_MODE and keyboard:
            keyboard.press(kc)
        elif bt_keyboard:
            bt_keyboard.press(kc)

    elif atype == "mod":
        # supports 2 or 3 keycodes e.g. ("mod", CTRL, SHIFT, K)
        keys = action[1:]
        _last_key_label = "Combo"
        if USB_MODE and keyboard:
            keyboard.press(*keys)
        elif bt_keyboard:
            bt_keyboard.press(*keys)

    elif atype == "string":
        text = action[1]
        _last_key_label = f"> {text[:12]}"
        if layout:
            layout.write(text)

    elif atype == "media":
        code = action[1]
        _last_key_label = "Media"
        if USB_MODE and consumer:
            consumer.press(code)
        elif bt_consumer:
            bt_consumer.press(code)

    elif atype == "layer":
        val = action[1]
        if val == "cycle":
            current_layer = (current_layer + 1) % len(keymap.LAYERS)
        else:
            current_layer = int(val) % len(keymap.LAYERS)
        _last_key_label = f">> Layer {current_layer}"
        refresh_display(current_layer, _last_key_label)
        return  # skip generic display refresh below

    refresh_display(current_layer, _last_key_label)


def do_release(action):
    """Release keys on key-up."""
    atype = action[0]
    if atype in ("key",):
        if USB_MODE and keyboard:
            keyboard.release(action[1])
        elif bt_keyboard:
            bt_keyboard.release(action[1])
    elif atype == "mod":
        keys = action[1:]
        if USB_MODE and keyboard:
            keyboard.release(*keys)
        elif bt_keyboard:
            bt_keyboard.release(*keys)
    elif atype == "media":
        if USB_MODE and consumer:
            consumer.release()
        elif bt_consumer:
            bt_consumer.release()


# ══════════════════════════════════════════════════════════════════════════════
# STARTUP
# ══════════════════════════════════════════════════════════════════════════════
# Startup animation — wipe LEDs layer color
startup_color = config.LAYER_COLORS[0]
for i in range(config.NEOPIXEL_COUNT):
    pixels[i] = startup_color
    pixels.show()
    time.sleep(0.03)
time.sleep(0.3)

refresh_display(current_layer)
print(f"[BOOT] MacroPad ready | {'USB' if USB_MODE else 'Bluetooth'} mode")


# ══════════════════════════════════════════════════════════════════════════════
# MAIN LOOP
# ══════════════════════════════════════════════════════════════════════════════
while True:
    now = time.monotonic()

    # BT reconnect if disconnected
    if not USB_MODE:
        try:
            if not ble.connected:
                if not ble.advertising:
                    ble.start_advertising(advertisement)
        except Exception:
            pass

    # Scan keys
    pressed_now = scan_matrix()
    pressed_set  = set(pressed_now)

    for key_idx in range(16):
        was_pressed = _prev_state[key_idx]
        is_pressed  = key_idx in pressed_set

        # Debounce
        if now - _debounce[key_idx] < config.DEBOUNCE_MS / 1000:
            continue

        layer_map = keymap.LAYERS[current_layer % len(keymap.LAYERS)]
        action    = layer_map[key_idx] if key_idx < len(layer_map) else ("none",)

        if is_pressed and not was_pressed:
            _debounce[key_idx]  = now
            _prev_state[key_idx] = True
            _last_activity       = now
            do_press(action)

        elif not is_pressed and was_pressed:
            _debounce[key_idx]  = now
            _prev_state[key_idx] = False
            do_release(action)

    # RGB update
    update_leds(current_layer, pressed_set)

    # Display sleep
    if config.DISPLAY_SLEEP_SEC > 0:
        if now - _last_activity > config.DISPLAY_SLEEP_SEC:
            dim_display()

    time.sleep(0.001)  # tiny yield so CircuitPython stays happy

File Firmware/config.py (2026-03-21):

# config.py — all your hardware settings live here
# Change this file to match your wiring, don't dig through code.py

import board

# ─── KEY MATRIX PINS ──────────────────────────────────────────────────────────
# 4x4 matrix — 4 rows, 4 cols = 16 keys
ROW_PINS = [board.GPIO1, board.GPIO2, board.GPIO3, board.GPIO4]
COL_PINS = [board.GPIO5, board.GPIO6, board.GPIO7, board.GPIO8]

# ─── NEOPIXEL ─────────────────────────────────────────────────────────────────
NEOPIXEL_PIN   = board.GPIO18   # Data pin for NeoPixels
NEOPIXEL_COUNT = 16             # One LED per key
NEOPIXEL_BRIGHTNESS = 0.3       # 0.0 – 1.0 (keep it low to not blind yourself)

# ─── OLED DISPLAY ────────────────────────────────────────────────────────────
OLED_SDA = board.GPIO9
OLED_SCL = board.GPIO10
OLED_WIDTH  = 128
OLED_HEIGHT = 64
OLED_ADDR   = 0x3C             # Default I2C address, try 0x3D if it doesn't show up

# ─── MODE SWITCH ──────────────────────────────────────────────────────────────
# This pin is read in boot.py to decide USB vs BT mode
# HIGH (pulled up) = USB HID   |   LOW (switch to GND) = Bluetooth
MODE_PIN = board.GPIO12

# ─── BLUETOOTH ────────────────────────────────────────────────────────────────
BT_DEVICE_NAME = "Dragon's Macro Pad"

# ─── DEBOUNCE ─────────────────────────────────────────────────────────────────
DEBOUNCE_MS = 20  

# ─── DISPLAY SLEEP ────────────────────────────────────────────────────────────
DISPLAY_SLEEP_SEC = 30  

# ─── RGB EFFECTS ──────────────────────────────────────────────────────────────
# Options: "solid", "rainbow", "breathe", "reactive"
RGB_EFFECT = "reactive"
RGB_IDLE_COLOR = (0, 80, 255)      # Blue idle glow
RGB_PRESS_COLOR = (255, 255, 255)  # White flash on keypress

# ─── LAYERS ───────────────────────────────────────────────────────────────────
# Colour shown on OLED and LEDs per layer
LAYER_COLORS = [
    (0, 80, 255),    # — Blue
    (0, 220, 80),    # — Green
    (255, 60, 0),    # — Orange
    (180, 0, 255),   # — Purple
]

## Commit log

2026-03-17 Initial KiCad Upload
    [NextGen Macropad.kicad_pcb, NextGen Macropad.kicad_sch]
2026-03-18 Uploading KiCad + Images + Production 180326-1005
    [Bottom Enclosure.step, Bottom Enclosure.stl, Case Source.blend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]
2026-03-18 KiCad Update
    [NextGen Macropad.kicad_pcb]
2026-03-19 Fix PCB + Add BOM
    [BOM.csv, NextGen Macropad.kicad_pcb, NextGen Macropad.kicad_sch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]
2026-03-20 New PCB Layout
    [NextGen Macropad.kicad_pcb, bom.csv, designators.csv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]
2026-03-21 KiCad Change
    [BOM.csv, NextGen Macropad.kicad_pcb]
2026-03-21 Firmware Push v1
    [BOM.csv]
2026-03-21 Folder Structure 210326-933
    [Top Plate.step, Top Plate.stl]
